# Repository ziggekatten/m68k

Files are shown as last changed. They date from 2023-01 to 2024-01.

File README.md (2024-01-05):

# Note to myself: I hate C pointers and macros.......
I have an blog where I will post my progress and thoughts when I have some spare time: https://brorson.se
# m68k
A overambitious project to build a usable computer from scratch. Based on bits and pieces from the interwebb, but with my own twists and turns. This main README will change frequently when I change my mind and decisions. 

It's not the goal that matters, is the journey....and it's true. Getting your thoughts and ideas into circuits and code is an iterative process, and for each success you get satisfaction. For every failure.....you get a reason for a big drink and rethink your decisions, just to fix the issue and start an new iteration. Add oh boy, the satisfaction when your idea works...priceless! 

Some decisions made from my part:

- Assembler is fun in small doses, so my plan is to NOT write firmware in assembler, but instead go down the C route and messing with sections and linkerscripts. Reason beeing that this will make me learn not only the various segments and the ELF format, but also how the GCC/LLVM toolchains works in more detail. I would like to use Zig (primary) or Rust (secondary), but as an non compiler wizard, this is currently on the backfoot, and O'l trusted C will do. There are some challenges though, that are quite simple in assembler, but when using C and segregation of duty, requires some more thoughts. For example, when using interrupts on the serial line, how do you pass the input from the exceptionhandler to your main kernel code? Simple answer one would say, some defined pseudo registers monitored by your main code in combination of global variables/structs in C. But this comes at an cost of CPU cycles as stuff needs to pass memory in several stages. Not easy decisions. Also, as I'm building some built in monitoring stuff in the firmwware to see values of stack pointer and register values, I might need to add som asssembler in the end. It will be inline if that's the case. It hurts, but unless I can use some GCC low level stuff I probably need to do this.
- Build my own stdlib based on newlib (https://sourceware.org/newlib/)
- Serial interface and an HW-monitor as initial I/0 path to the SBC 

Initial hardware:
- CPU: MC68010@12MHz
- DUART: MC68681
- 2 * 512K FLASH ROM
- 2 x 512K SRAM
- A bunch of 74LS/HCT chips
- A bunch of breadboards
- Some PAL/GAL's to replace discrete glue logic in the end
- Reset circuitry based on 555 timer and with both a reset button as well as an single step function, using DTACK.

## Some loose thoughts
- Use ELF as a base segment standard instead of Motorola S-records. This means that i need to steal someone elses ELF loader I guess... 
- When basic serial I/O is done. It's time to look at keyboard input as well as graphics display. The keyboard stuff is easy enough if using PS/2 standard. The graphics stuff however is a little bit more complicated. Signal wise it is easy, just output the correct voltages and Bob's your uncle. But getting data in a format that does not bog down CPU to some memory mapped hardware, and the get the display circuit to effectively interpret data and do stuff, is a different story. Text based stuff are easy using predetermined fonts, but The 680x0 CPU is not capable to feed pixel data at rates needed if just pushing pixels, so there have to be stuff in between. Amigas, Ataris and others have this done in custom chips, which means that I have to do it in an similar way. But this is where I draw the line (pun intended) and don't design my own blitter, copper etc. I will probably interface to already done parts, using APIs or existing hardware designs. In the end, designing at this level means also supply low level libraries and stuff. However, an pure vector based drawing design is in my head, so one never know....

## Memory map of the design
I keep it simple, and plan using the VBR register in the MC68010, so there is no shadowing or moving of ROM in my design.

| Address | Description |
|---|---|
| 0x00000000 - 0x000FFFFF | ROM ( 2 x 512K) |
| 0x00100000 - 0x001FFFFF | Onboard RAM (1 MB) |
| 0x00200000 - 0x00CFFFFF | Space for additional (14 MB) RAM |
| 0x00D00000 - | I/O space  (2 MB) | 
| 0x00D00000 - 0x00D0FFFF | DUART (64KB) |

## Codebase
I have switched to use https://github.com/tomstorey/m68k_bare_metal as base for my project instead of inventing all by myself. Sure, my linkerscript, Makefile and stuff was not bad, but was very bare bone. Even if there are a little more assembly, the structure is is more usable as defining exception vectors and stuff are easier. So instead of continuing and reinvent the wheel, I made the choice to use som clever stuff from github. Tom, you made me see a different (and more professional) way of doing stuff by the way you structured your code. Especially the linkerscript was an huge improvement over my amateur cocktail of C code.

All old firmware code are now in the /old_stuff folder and all new under /mb68k_bare_metal/mb68k
My headerfiles used for my specific board is located under /mb68k_bare_metal/include

## Version history
0.1.10 - Use of new approach for using C and design wise introducing buffers and more GALs 

0.1.9 - A lot of reshuffeling

0.1.8 - Switched to PlatformIO for Arduino stuff

0.1.7 - Got the firmware to configure DUART and spit out stuff on the terminal in sim68000 using pure C. Hardware is tested in an sense that I can control the DUART from an Arduiono Mega, and the CPU stuff on the breadboard is free running, and are awaiting the pairing of DUART and firmware code.

0.1.6 - Cleaned upp some code and added some README stuff. All prototypes now in headers.

0.1.5 - Just cleaning stuff

0.1.4 - Milestone. Got my bare Firmware (just ending in an loop) running in sim68000

0.1.3 - Just a bunch of renaming and updates of README files. In essence, cleaning up my own mess

0.1.2 - Milestone. I finally got the grips on gcc, linkerscripts, .map files etc. Building an ELF and object dump an binary now generates binary file with an valid reset vector and correct sections copied to RAM. What a fun ride it have been.

0.1.1 - Milestone. Got a free running CPU stepping through memory and blinking leds, by tying databus to ground (all zeros) throug pulldown resistors

## Toolchain(s) and emulators/simulators
Currently using GCC on Ubuntu 20.04 cross compiled for m68k.
In parallel building an LLVM toolchain for exploring the capabilities of using Rust and/or Zig instead of C. This is somewhat in an experimental phase, as some basic compilation efforts on LLVM and Rust/Zig is currently beeing tried out. My toolchains run in docker, and Dockerfiles can be found in the [toolchains] folder.

## Folder structure
| Folder | Description |
|---|---|
| code | Code for firmware and other stuff goes in here |
| kicad | KiCAD 7.x schematics |
| digital | Digital simulator for messing with glue logic and generation WinCUPL code in the end |
| toolchains | Things related to toolchains. Docker files etc |
| tests | Arduino stuff used to test and program various parts of the design |

## Some experiences to share

MC68000/10 memory mapping and external pheripherals are always an challenge. That said, the m68k has the most beautiful register/memory layout and assembler syntax known to man. If todays CPU's had this layout, ohh man... Normally external peripherals only use a few address lines and more importantly only half the data bus (unless on an MC68008). What this means is that you really need to understand how the processor address memory and in which order it's doing stuff. First of all, as you might have noted on the CPU there is no address line of 0. First physical address line is A1, which will cause som confusion to newbies (as it did to me!). To explain this we need to understand two other physical pins on the CPU: UDS and LDS. UDS means Upper Data Strobe, and LDS means Lower Data Strobe. These pins define if you are in the upper 8-bit or lower 8-bit of an word (16 bit). 

Now, this is what caught me, since the CPU is Big Endeian, even adresses is always the upper 8-bits. Easiest way of explain this is by starting at at the lowest address in hex: 0x00000000. This is an even address, and accessing this address will assert the UDS-pin signaling that the upper 8-bits of the data bus will be read/written from/to (bit 15-8). When designing your memory map, things can be confusing. Let us say that memory 0x00000000 to 0x000FFFFF is your first MB of RAM, and you think that address 0x00100000 is the first byte in the I/O space, you would be wrong. Address 0x00100000 is the upper 8-bits of the 16-bit word, and if you have the pheriperal connected to the D0-D7, the effective address is actually 0x00100001!. 

What this means is, that you need to take care when accessing 8-bit memory mapped peripherals. Let us take an simple example here using the MC68681 DUART chip as an example. It has an 4-bit addressing bus for it's registers that we normally connect to A1-A4, and an 8-bit address bus, connected to the A0-A7 physical bus. According to the documentation the registers are one byte in between on the chip itself. 

But this is not true in the scope of the CPU, as the most significant byte is never seen by the chip. It sees A1, not A0(UDS). In effect, this means that your code needs to have an offset of two(2) whereas the chip has an offset of only one(1).
In general, working with bytes is an pain as you need to think about alignment, and if possible use words....

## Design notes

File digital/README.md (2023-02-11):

## Memory map and glue logic
I use Digital (https://github.com/hneemann/Digital) to do alot of digital circuit designs, and it also have the very conveniant feature of generating circuits from truth tables, and then create .JED files for the GAL's that I'm using (GAL22v10D from Lattice).

| File | Description |
|---|---|
| address_decoder_gal.tru | Truth table for address decoding meant for GAL22v10D |
| memorydecoding.dig | This is an design based on multiplexers (74LS138) instead of an GAL |

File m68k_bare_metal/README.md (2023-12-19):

# Bare Metal m68k Cross Compiler "Toolchain"
- [Bare Metal m68k Cross Compiler "Toolchain"](#bare-metal-m68k-cross-compiler--toolchain-)
  * [Motivation](#motivation)
  * [My solution](#my-solution)
  * [How To Use](#how-to-use)
    + [Get started (installation)](#get-started-installation)
    + [Build libmetal](#build-libmetal)
    + [Create a "project"](#create-a-project)
    + [Linker script](#linker-script)
    + [Write some code already...](#write-some-code-already...)
    + [Notes about floating point](#notes-about-floating-point)
  * [Additional tools](#additional-tools)
- [Advanced Topics](#advanced-topics)
  * [Default interrupt handler](#default-interrupt-handler)
  * [Exception handling routines](#exception-handling-routines)
  * [Interrupt Service Routines](#interrupt-service-routines)
- [Anything Else](#anything-else)
  * [TODOs](#todos)

This repository contains my efforts to create an "idiot proof bare metal m68k cross compiler toolchain of sorts."

Please be advised that I am not a makefile or linker script expert in any way, and the fact this works at all may just be sheer luck. If you have suggestions how I can better or more properly achieve what I have, I would be very appreciative to hear from you. In the mean time, please be gentle. :-)

## Motivation
There are a lot of tools out there that can create cross compiler environments for all sorts of architectures on all sorts of architectures. If you work as a software developer, these tools might make a lot of sense, and may be the right way to go about things.

But as a lowly hobbyist that dabbles in both software and hardware and is certainly a master of neither, I find these tools quite complicated and often hard to get my head around what they are doing and how to use them. I want something simpler.

## My Solution
My solution to the problem was to create something (hopefully) so simple that ideally anyone else like me out there could understand how it is working, and also be able to modify it to suit their needs.

In my solution, I want to take some C source files (and perhaps some assembly source files, too), compile them, link them together, and produce a binary image out the other side that can be loaded directly into ROM and placed into a system and run.

To achieve this I have made a minimal linker script that allows you to position and dimension your ROM and RAM memories as required. The linker script also pulls in a reasonably vanilla flavoured `crt0` that I made, and creates the exception vector table (including reset vector).

Also included is a `Makefile` to help make building your code easier. Essentially the only thing you need to do with the Makefile is list each of the object file names that will be linked together to produce your binary (the compiler, `gcc` in my case, takes care of working out the details including dependencies for C source files).

Other than that, you just start writing code and run `make`! I think that's pretty simple.

## How To Use
There are two different "build environment flavours" that you can choose from:

 - **standalone**: this is a build that will run by itself on your system. It will include a exception vector table (EVT), and program code (crt0, your code, read only/constant data, initialised variables)
 - **application**: this is a build that might, for example, run along side a standalone build. This kind of build includes all of the above with the exception of a pared down crt0 and excludes the EVT

The idea behind these two different builds comes down to how you might build and write software for a bare metal system. For example, you may use a standalone build to implement some kind of operating system or monitor, and perhaps this allows you to load in code over a serial link and execute it. That code may be some kind of application that you want to test and debug, and which itself does not require an EVT.

### Get started (installation)
You can build or install the required tools on a variety of operating systems. Installation instructions are broken out by operating system (or group of) as each is a little different to the last, so please refer to the appropriate INSTALL-xxxx.md file in this repo.

At the time of writing, the tool chain is known to work on the following operating systems:

 - Ubuntu 18.04 and 20.04
 - Debian 9.12 and 10
 - Windows 10 with WSL
 - macOS High Sierra (10.13), Catalina (10.15), Big Sur (11.6)

### Build libmetal
libmetal is just a "libc like library" that I have put together including a lot of standard libc style functions. Included is a `printf` (credit: https://github.com/eyalroz/printf) and `malloc` (credit: own work, inspired by FreeRTOS).

libmetal should only need to be built once per CPU type, and is then used in all of your future projects using that CPU. If further source files or changes to source files are made within libmetal, then you will need to rebuild it for each CPU type that you intend to use.

To build libmetal, simply run `make` within the `libmetal` directory. Provided there are no blocking errors, you will be left with a file called `libmetal-xxxx.a` (where xxxx is the CPU type), and at that point you are done.

Dont forget to modify the CPU type and select your gcc prefix in the `Makefile` as required - the CPU type influences the output filename, as each copy of libmetal is built specific to that CPU.

### Create a "project"
Really this is just as simple as making a copy of either the `standalone` or `application` directory, and naming it appropriately. You'll then work on the files in this directory.

```
~$ cd m68k_bare_metal
~/m68k_bare_metal$ cp -a standalone myproject
~/m68k_bare_metal$ cd myproject
~/m68k_bare_metal/myproject$ ls -la
-rw-r--r-- 1 tom tom 1456 May 31 14:52 Makefile
-rw-r--r-- 1 tom tom 3376 May 31 14:52 crt0.S
-rw-r--r-- 1 tom tom   54 May 31 14:52 main.c
-rw-r--r-- 1 tom tom 5540 May 31 14:52 platform.ld
```

Open `Makefile` in your favourite editor and modify the CPU and PREFIX variables as required for your target and environment.

Once you have done this, the first thing to do is to assemble `crt0.S`. Take a quick look at the very beginning of this file and determine if there are any settings that you want to change for your situation, otherwise, run:

```
~/m68k_bare_metal/myproject$ make crt
```

You'll then notice a file called `crt.o` in your project directory. This object file is needed by the linker, and is the first code that will execute when the system starts up. `crt0` is responsible for (in a standalone build):

* ensuring interrupts are masked by default
* setting up the stack pointer (manually, notes included)
* copying the EVT to RAM at address 0 or configuring the VBR as/if required
* copying the values of initialised variables into their appropriate memory locations
* clearing the .bss section
* calling soft and hard initialisation hooks

After all of this, it then jumps to your `main()` routine. In an application build, `crt0` only copies initialised variables into RAM, zeroises the .bss section (uninitialised variables) and jumps to `main()`.

### Linker script
The default linker script configuration places ROM at address 0 with a size of 0x100000 (1 megabyte), and RAM at 0x100000 with a size of 0x100000. Space is also reserved for the stack which is initialised to the top of RAM, and all remaining space will be allocated to the heap.

You may need to modify these values to suit your system and application memory layout and requirements. If you do, be sure to `make clean` and rebuild your project to ensure that the new memory layout is updated in your binary. It is not necessary to rebuild crt0 if you simply modify the memory layout.

To do this, open `platform.ld` in your preferred editor, and look at the `base` and `sz` variables at the top of the file. Modify these as required.

 - `base` refers to the very first memory address of that memory type
 - `sz` refers to the number of bytes provided by that memory

The SSP (Supervisor Stack Pointer) will be initialised to the very top of memory, thus assuming that the stack grows downwards with pre-decrement. Therefore, in the default configuration, the SSP will point to 0x200000, and the first value to be pushed to the stack will be written to 0x1FFFFC (long) or 0x1FFFFE (word).

The initial PC (Program Counter) value will point to the address of `_start`, which is located in `crt0.S`.

The linker script also generates an exception vector table (EVT), and this will be located through addresses 0-0x3FF (0-1023) in the ROM. Each entry in the EVT is a long (4 bytes) which points to an address where the code that handles that exception or interrupt is located. When an interrupt or execption occurrs, the processor reads the corresponding EVT entry and then jumps to the address contained within.

Both the SSP and initial PC values are stored as the very first two longs in the EVT, e.g. from addresses 0-7.

All of the documented exception vectors are pre-configured in the linker script, but if you need to add more, e.g. for your UARTs and other devices, then they can be defined manually in the linker script. See the documentation included within the linker script for an example of how to do that.

Note that while the ROM does not have to always exist from address 0, it will need to exist there initially as the m68k needs to read the SSP and initial PC values starting from address 0. If you require RAM to be located at address 0 in your system, you will need to implement circuitry or some software means to switch the ROM to a higher address. You will also then need to ensure that address range 0-0x3FF in RAM is populated with the EVT required for your system - `crt0` largely takes care of this automatically by either setting the Vector Base Register (VBR) on CPUs that have it, or copying the EVT.

These are the only changes to the linker script required, but you are free to experiment if you wish (or dare).

### Write some code already...
Ok, with all of the setup of your environment completed, you can now being to write code.

Included is a very simple `main.c`, so you can test that everything is working simply by running `make`. If all is successful, you should see a file called `bmbinary`.

```
~/m68k_bare_metal/myproject$ make
m68k-linux-gnu-gcc -m68000 -Wall -g -static -I. -msoft-float -MMD -MP -c -o main.o main.c
m68k-linux-gnu-ld -o bmbinary main.o --script=platform.ld
~/m68k_bare_metal/myproject$ ls -la
-rw-r--r-- 1 tom tom  1456 May 31 14:52 Makefile
-rwxrwxr-x 1 tom tom 19056 May 31 14:54 bmbinary
-rw-rw-r-- 1 tom tom  2136 May 31 14:53 crt0.o
-rw-r--r-- 1 tom tom  3376 May 31 14:52 crt0.S
-rw-r--r-- 1 tom tom    54 May 31 14:52 main.c
-rw-rw-r-- 1 tom tom    15 May 31 14:54 main.d
-rw-rw-r-- 1 tom tom  2112 May 31 14:54 main.o
-rw-r--r-- 1 tom tom  5540 May 31 14:52 platform.ld
```

If this works without any errors you are off to a very good start. From here you can proceed to write further code, and create additional source files. Worth noting, dependencies for .c files are automatically generated.

For each source file that you create, you will need to add it to `Makefile` in order for it to be compiled and linked.

Fortunately this is a very simple process, and all you need to do is add what will be the corresponding object filename (.o) to a variable at the top of the Makefile. Instructions are included to demonstrate how you should do this.

Once you are finished writing code and are ready to run it in your system, running `make rom` will output a file called `bmbinary.rom` which can be written to your ROMs and installed in the system.

### Notes about floating point
Most 68000 family CPUs do not include a floating point unit, and many systems do not include an external FPU either. Getting soft float to work in this toolchain has been a challenge, and I'm still not quite there yet. If you are able to help get this working, I'd love to hear from you!

Long story short, floating point may or may not work!

## Additional tools
The Makefile includes some extra rules to help with your development, these are:

 - `make dump` displays a disassembly of `bmbinary`
 - `make dumps` displays a disassembly of `bmbinary` with source code intermixed
 - `make hexdump` will produce a hex dump of `bmbinary.rom`
 - `make clean` will remove all `.o`, `.d`, and the `bmbinary` and `bmbinary.rom` files from your project directory (except `crt0.o`)

# Advanced Topics
**Note:** Most of what is written below applies only to standalone builds, as application builds do not include an EVT.

## Default interrupt handler
By default, all documented exception vectors will point to a default interrupt handling routine, which is included in `crt0.S`, called `__DefaultInterrupt`.

The default handler simply halts the CPU and masks all IRQs below IRQ7, but this is not likely to be the desired behaviour that a user may want. Therefore, the user needs to create their own service routines to handle them.

The linker script builds the EVT based on the presence or absence of each expected service routine. If a service routine is not defined, then its vector table entry points to `__DefaultInterrupt`, otherwise the entry points to the address of the routine in the ROM image.

You can of course modify or override `__DefaultInterrupt` if you desire some other default behaviour.

## Exception handling routines
If you look in `platform.ld` you will see a list of all of the exception handling routine names that are expected. These can be changed if you would prefer different names.

To ensure that your code handles each exception in the way you would prefer, simply create a routine with the name as described in the linker script. For example, if you would like to handle a divide by zero exception, you would create the following routine:

```c
void __attribute__((interrupt))
ZeroDivide(void)
{
    /* Your code here */
}
```

Exception handlers do not return a value, so they are void. They also do not take any parameters. `__attribute__((interrupt))` tells the compiler to insert the correct return instruction, `rte` instead of `rts`, when returning from an interrupt.

If you were to then run `make` and then `make dump` to view the disassembly, you would notice that the EVT has been populated with an entry that points to the ZeroDivide routine you created, for example:

```
~/m68k_bare_metal/myproject$ make dump
...
Contents of section .evt:
 0010 00000470 00000482 00000470 00000470  ...p.......p...p...
00000482 <ZeroDivide>:
 482:   4e56 0000       linkw %fp,#0
 486:   4e71            nop
 488:   4e5e            unlk %fp
 48a:   4e73            rte
 ...
```

As you can see, rather than pointing to the default interrupt handler at 0x00000470, one entry corresponding to the divide by zero exception now points to 0x00000482.

And thats basically all there is to that. Happy error handling!

## Interrupt Service Routines
To handle a vectored interrupt, you must create an ISR, and also create the appropriate vector table entry in the linker script.

To begin with, in your C file, you can create your ISR as follows:

```c
void __attribute__((interrupt))
my_interrupt_handler(void)
{
    /* Your code here */
}
```

And like exception handlers, ISRs return nothing and have no parameters, so are void. Likewise, the interrupt attribute tells the compiler to use the correct return instruction for this routine.

Now, in the linker script you will need to create an entry to be placed in the EVT. Documentation is included, but lets use another example. Say we want our interrupt vector to be 0x80, we would create our entry as follows:

 - Vector numnber 0x80
 - Multiply by 4 to get a physical address of 0x200
 - Results in origin of 0x200 within the `.evt` section

Therefore we add the following to the linker script:

```
SECTIONS {
	...
    .evt : {
	...
        . = 0x200;
        LONG(ABSOLUTE(my_interrupt_handler));
    } > evt
	...
}
```

Re-compiling our code and inspecting the disassembly we should then expect to see something like the following:

```
~/m68k_bare_metal/myproject$ make dump
...
Contents of section .evt:
 0200 0000048c                             ....
...
0000048c <my_interrupt_handler>:
 48c:   4e56 0000       linkw %fp,#0
 490:   4e71            nop
 492:   4e5e            unlk %fp
 494:   4e73            rte
	...
```

Happy interrupt vectoring!

# Anything Else
Please file an issue with me for any questions you have, I'll do my best to help.

## TODOs
 - Integrate a GDB stub for debugging

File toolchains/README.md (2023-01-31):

# Toolchains and simulators/emulators!

Some useful stuff related to Simulators nad toolchains. Let us start with...

## Simulators
Yes, especially simulators are gold when developing for homebrew hardware. Popping flash ROM in an out of breadboards are tedious, and by chance I stumbled over the sim6000 simulator. An simulator written in C++ and Tcl/tk, but it has two brilliant features:
- Simulation of an mc68681 DUART, with selectable base address! This is golden to test stuff in software. Loads Motorola S-records and of you go. 
- Multiple definable memory areas

The code can be found at: https://github.com/BSVC/bsvc
clone, make and make install and you are up and running. Requires wish and xterm though (apt install xterm wish on Ubuntu or in my case, latest version of Pop!_OS), and the UI...well, time have not been friendly to this app....but it works! It booted my firmware completely written in C. Now I can start messing with serial stuff. It comes with ssome samples including Tutor(!) using an xterm as serial I/O.

TODO: Maybe evolve this codebase and udate UI???

Apart from that, the EASy68k emulator is a good tool if you are into assembler and no pheripherals. The UI is WAY better than sim68000, but no peripherals built in. You can find it here: http://www.easy68k.com/

## Toolchains

Instead of messing up your local linux install or VM's, usage of containers is an pragmatic way for running toolchains.
Several options exists, and this repo have currently three different ones to pick from. Two versions of LLVM for future use of zig and/or rust instead of C.
Third option is to use the toolchan created by: https://rosco-m68k.com/ 

- Dockerfile.15: LLVM 1.15.x build with m68k support. To be used with zig (experimental and not complete!!!)
- Dockerfile.16: LLVM 1.16.x build with m68k support. To be used with rust (experimental and not complete!!!)
- Dockerfile.rosco: A containerized implementation of Rosco SBC toolchain https://rosco-m68k.com/docs/toolchain-installation

Are you an Windows purist and don't use Docker, WSL or an Linux VM, there is an precompiled setup available at: https://gnutoolchains.com/m68k-elf. Built with older versions f GCC and newlib, but still a working toolchain.

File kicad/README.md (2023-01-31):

# Hardware design

Basic principles:
- Use of buffers when in doubt. The 68010 pins can't drive that much current 

TODO: description

- CPU: MC68010@12MHz
- DUART: MC68681
- 2 * 512K FLASH ROM
- 2 x 512K SRAM

## Memory map

TODO: description

| Start address (hex) | End address (hex) | Usage |
|:---:|:---:|:---:|
|0x00100000 |0x00200000 | Onboard RAM |
|0x00000000 |0x00100000 | Onboard ROM |

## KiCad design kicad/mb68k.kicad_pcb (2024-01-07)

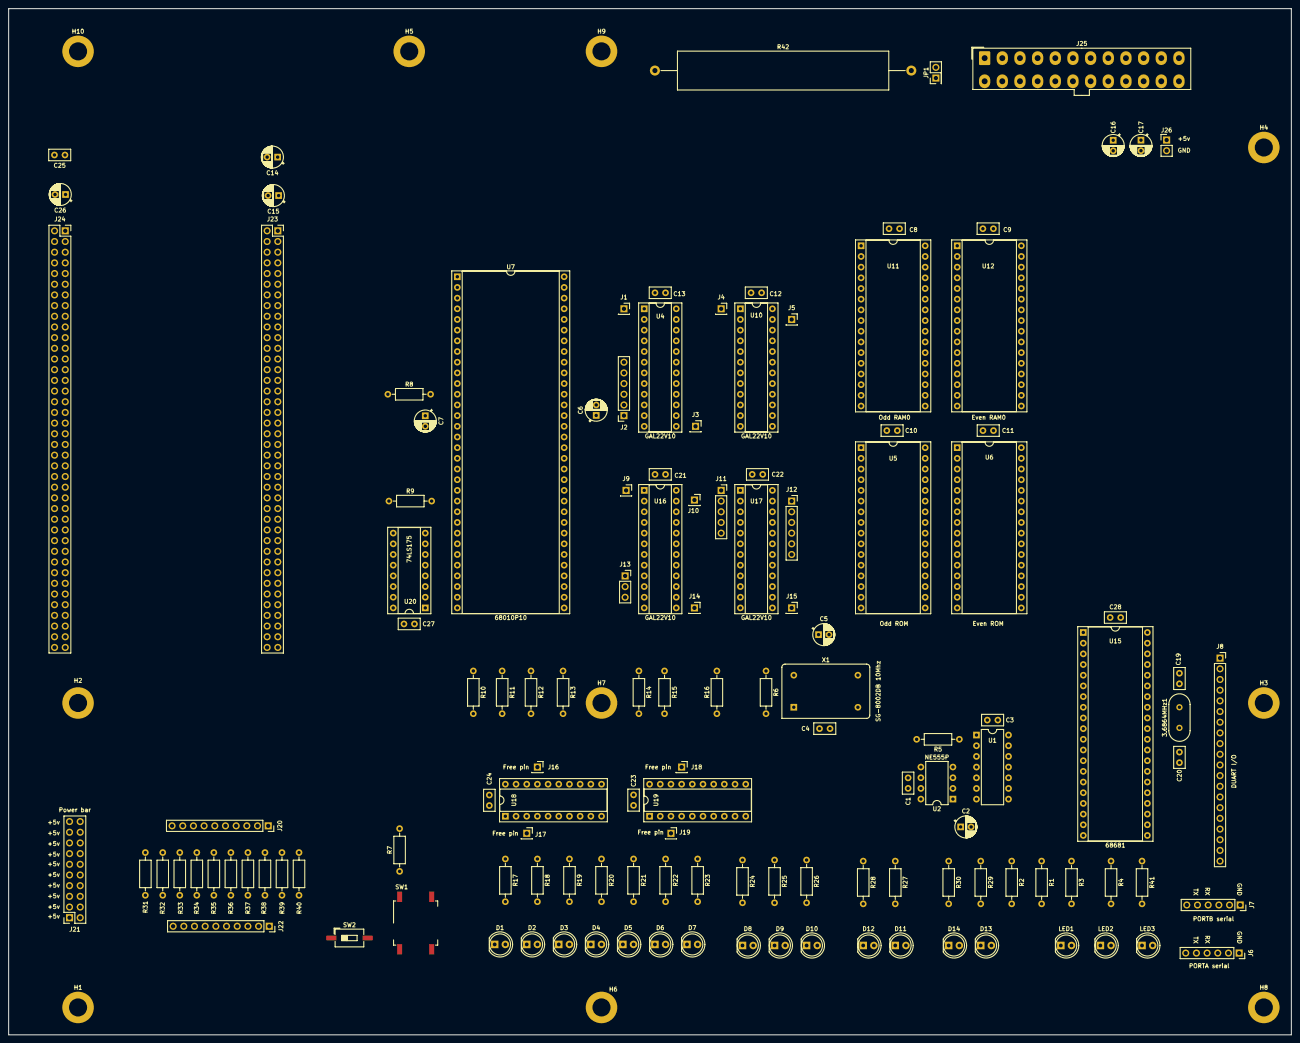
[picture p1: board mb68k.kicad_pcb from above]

Board: 4 copper layers, 305.0 x 244.0 mm, 142 parts (0 on the bottom side), 199 nets, no tracks yet.

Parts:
3.6864MHz1: Crystal; Crystal_HC18-U_Vertical
C1, C3, C4, C8, C9, C10, C11, C12, C13, C21, C22, C23, C24, C27, C28: 100nF; C_Disc_D5.0mm_W2.5mm_P2.50mm
C2, C16: 100uF; CP_Radial_D5.0mm_P2.50mm
C5, C6, C7, C15, C26: 100nF; CP_Radial_D5.0mm_P2.50mm
C14: 10uF; CP_Radial_D5.0mm_P2.50mm
C17: 470uF; CP_Radial_D5.0mm_P2.50mm
C19, C20: 7pF; C_Disc_D5.0mm_W2.5mm_P2.50mm
C25: 10uF; C_Disc_D5.0mm_W2.5mm_P2.50mm
D1: IRQ1; LED_D5.0mm
D2: IRQ2; LED_D5.0mm
D3: IRQ3; LED_D5.0mm
D4: IRQ4; LED_D5.0mm
D5: IRQ5; LED_D5.0mm
D6: IRQ6; LED_D5.0mm
D7: IRQ7; LED_D5.0mm
D8: FC1; LED_D5.0mm
D9: FC2; LED_D5.0mm
D10: FC3; LED_D5.0mm
D11: DUARTA_RX; LED_D5.0mm
D12: DUARTA_TX; LED_D5.0mm
D13: DUARTB_RX; LED_D5.0mm
D14: DUARTB_TX; LED_D5.0mm
H1, H2, H3, H4, H5, H6, H7, H8, H9, H10: MountingHole_Pad; MountingHole_4.3mm_M4_DIN965_Pad
J1, J3, J4, J5, J9, J10, J14, J15, J16, J17, J18, J19: Free pin; PinSocket_1x01_P2.54mm_Vertical
J2, J12: Free pins; PinSocket_1x06_P2.54mm_Vertical
J6: PORTA serial; PinSocket_1x06_P2.54mm_Vertical
J7: PORTB serial; PinSocket_1x06_P2.54mm_Vertical
J8: DUART I/O; PinSocket_1x20_P2.54mm_Vertical
J11: Free Pins; PinSocket_1x05_P2.54mm_Vertical
J13: Free pins; PinSocket_1x03_P2.54mm_Vertical
J20, J22: Spare resistors; PinSocket_1x10_P2.54mm_Vertical
J21: Power bar; PinSocket_2x10_P2.54mm_Vertical
J23: BUS Slot 2; PinSocket_2x40_P2.54mm_Vertical
J24: BUS Slot 1; PinSocket_2x40_P2.54mm_Vertical
J25: ATX-24; Molex_Mini-Fit_Jr_5566-24A_2x12_P4.20mm_Vertical
J26: External Power; PinHeader_1x02_P2.54mm_Vertical
JP1: BASE LOAD; PinHeader_2x01_P2.54mm_Vertical
LED1: RED Reset; LED_D5.0mm
LED2: GREEN Run; LED_D5.0mm
LED3: GREEN PWR; LED_D5.0mm
R1, R2, R6: 4K7; R_Axial_DIN0207_L6.3mm_D2.5mm_P10.16mm_Horizontal
R3, R4: 330R; R_Axial_DIN0207_L6.3mm_D2.5mm_P10.16mm_Horizontal
R5: 2K2; R_Axial_DIN0207_L6.3mm_D2.5mm_P10.16mm_Horizontal
R7: 270R; R_Axial_DIN0207_L6.3mm_D2.5mm_P10.16mm_Horizontal
R8, R9, R10, R11, R12, R13, R14, R15, R16, R31, R32, R33, R34, R35, R36, R37, R38, R39, R40: 4k7; R_Axial_DIN0207_L6.3mm_D2.5mm_P10.16mm_Horizontal
R17, R18, R19, R20, R21, R22, R23, R24, R25, R26, R27, R28, R29, R30, R41: R330; R_Axial_DIN0207_L6.3mm_D2.5mm_P10.16mm_Horizontal
R42: R10 14W; R_Axial_Power_L50.0mm_W9.0mm_P60.96mm
SW1: HW_RESET_SW; SW_MEC_5GSH9
SW2: POWER ON; SW_DIP_SPSTx01_Slide_6.7x4.1mm_W8.61mm_P2.54mm_LowProfile
U1: 74LS05; DIP-14_W7.62mm
U2: NE555P; DIP-8_W7.62mm
U4, U10, U16, U17: GAL22V10; DIP-24_W7.62mm_Socket
U5, U6: SST39SF040; DIP-32_W15.24mm_Socket
U7: 68010P10; DIP-64_W25.4mm_Socket
U11, U12: AS6C4008-55PCN; DIP-32_W15.24mm_Socket
U15: 68681; DIP-40_W15.24mm_Socket
U18, U19: 74LS244; DIP-20_W7.62mm_Socket
U20: 74LS175; DIP-16_W7.62mm_Socket
X1: SG-8002DB 10Mhz; Oscillator_DIP-14

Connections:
A1: J23.47, J24.47, U5.12 (A0), U6.12 (A0), U7.29 (A1), U11.12 (A0), U12.12 (A0), U15.1 (RS1), U16.5 (I4)
A2: J23.45, J24.45, U5.11 (A1), U6.11 (A1), U7.30 (A2), U11.11 (A1), U12.11 (A1), U15.3 (RS2), U16.6 (I5)
A3: J23.43, J24.43, U5.10 (A2), U6.10 (A2), U7.31 (A3), U11.10 (A2), U12.10 (A2), U15.5 (RS3), U16.7 (I6)
A4: J23.41, J24.41, U5.9 (A3), U6.9 (A3), U7.32 (A4), U11.9 (A3), U12.9 (A3), U15.6 (RS4)
A5: J23.39, J24.39, U5.8 (A4), U6.8 (A4), U7.33 (A5), U11.8 (A4), U12.8 (A4)
A6: J23.37, J24.37, U5.7 (A5), U6.7 (A5), U7.34 (A6), U11.7 (A5), U12.7 (A5)
A7: J23.35, J24.35, U5.6 (A6), U6.6 (A6), U7.35 (A7), U11.6 (A6), U12.6 (A6)
A8: J23.33, J24.33, U5.5 (A7), U6.5 (A7), U7.36 (A8), U11.5 (A7), U12.5 (A7)
A9: J23.31, J24.31, U5.27 (A8), U6.27 (A8), U7.37 (A9), U11.27 (A8), U12.27 (A8)
A10: J23.29, J24.29, U5.26 (A9), U6.26 (A9), U7.38 (A10), U11.26 (A9), U12.26 (A9)
A11: J23.27, J24.27, U5.23 (A10), U6.23 (A10), U7.39 (A11), U11.23 (A10), U12.23 (A10)
A12: J23.25, J24.25, U5.25 (A11), U6.25 (A11), U7.40 (A12), U11.25 (A11), U12.25 (A11)
A13: J23.23, J24.23, U5.4 (A12), U6.4 (A12), U7.41 (A13), U11.4 (A12), U12.4 (A12)
A14: J23.21, J24.21, U5.28 (A13), U6.28 (A13), U7.42 (A14), U11.28 (A13), U12.28 (A13)
A15: J23.19, J24.19, U5.29 (A14), U6.29 (A14), U7.43 (A15), U11.3 (A14), U12.3 (A14)
A16: J23.17, J24.17, U5.3 (A15), U6.3 (A15), U7.44 (A16), U10.10 (I9), U11.31 (A15), U12.31 (A15)
A17: J23.15, J24.15, U5.2 (A16), U6.2 (A16), U7.45 (A17), U10.11 (I10), U11.2 (A16), U12.2 (A16)
A18: J23.13, J24.13, U5.30 (A17), U6.30 (A17), U7.46 (A18), U10.14 (I/O), U11.30 (A17), U12.30 (A17)
A19: J23.11, J24.11, U5.1 (A18), U6.1 (A18), U7.47 (A19), U10.15 (I/O), U11.1 (A18), U12.1 (A18)
A20: J23.9, J24.9, U7.48 (A20), U10.2 (I1)
A21: J23.7, J24.7, U7.50 (A21), U10.3 (I2)
A22: J23.5, J24.5, U7.51 (A22), U10.4 (I3)
A23: J23.3, J24.3, U7.52 (A23), U10.5 (I4)
CLK: J23.4, J24.4, U7.15 (CLK), X1.8 (OUT)
D0: J23.40, J24.40, U5.13 (D0), U7.5 (D0), U11.13 (DQ0), U15.25 (D0)
D1: J23.38, J24.38, U5.14 (D1), U7.4 (D1), U11.14 (DQ1), U15.16 (D1)
D2: J23.36, J24.36, U5.15 (D2), U7.3 (D2), U11.15 (DQ2), U15.24 (D2)
D3: J23.34, J24.34, U5.17 (D3), U7.2 (D3), U11.17 (DQ3), U15.17 (D3)
D4: J23.32, J24.32, U5.18 (D4), U7.1 (D4), U11.18 (DQ4), U15.23 (D4)
D5: J23.58, J24.58, U5.19 (D5), U7.64 (D5), U11.19 (DQ5), U15.18 (D5)
D6: J23.60, J24.60, U5.20 (D6), U7.63 (D6), U11.20 (DQ6), U15.22 (D6)
D7: J23.62, J24.62, U5.21 (D7), U7.62 (D7), U11.21 (DQ7), U15.19 (D7)
D8: J23.64, J24.64, U6.13 (D0), U7.61 (D8), U12.13 (DQ0)
D9: J23.66, J24.66, U6.14 (D1), U7.60 (D9), U12.14 (DQ1)
D10: J23.68, J24.68, U6.15 (D2), U7.59 (D10), U12.15 (DQ2)
D11: J23.70, J24.70, U6.17 (D3), U7.58 (D11), U12.17 (DQ3)
D12: J23.72, J24.72, U6.18 (D4), U7.57 (D12), U12.18 (DQ4)
D13: J23.74, J24.74, U6.19 (D5), U7.56 (D13), U12.19 (DQ5)
D14: J23.76, J24.76, U6.20 (D6), U7.55 (D14), U12.20 (DQ6)
D15: J23.78, J24.78, U6.21 (D7), U7.54 (D15), U12.21 (DQ7)
E: U7.20 (E), U20.9 (Cp)
FC0: U7.28 (FC0), U16.2 (I1), U19.2 (I0a)
FC1: U7.27 (FC1), U16.3 (I2), U19.4 (I1a)
FC2: U7.26 (FC2), U16.4 (I3), U19.6 (I2a)
GND: C2.2, C3.2, C4.2, C5.2, C6.2, C7.2, C8.2, C9.2, C10.2, C11.2, C12.2, C13.2, C14.2, C15.2, C16.2, C17.2, C19.1, C20.1, C21.2, C22.2, C23.2, C24.2, C25.2, C26.2, C27.1, C28.2, H1.1, H2.1, H3.1, H4.1, H5.1, H6.1, H7.1, H8.1, H9.1, H10.1, J6.1, J7.1, J8.1, J21.2, J21.4, J21.6, J21.8, J21.10, J21.12, J21.14, J21.16, J21.18, J21.20, J23.2, J23.42, J24.2, J24.42, J25.3 (GND), J25.5 (GND), J25.7 (GND), J25.15 (GND), J25.17 (GND), J25.18 (GND), J25.19 (GND), J25.24 (GND), JP1.1 (A), R7.2, R24.1, R25.1, R26.1, R27.1, R28.1, R29.1, R30.1, R41.1, SW2.1 (A), U1.7 (GND), U2.1 (GND), U4.12 (GND), U5.16 (GND), U6.16 (GND), U7.16 (GND), U7.53 (GND), U10.12 (GND), U11.16 (VSS), U12.16 (VSS), U15.20 (GND), U16.12 (GND), U17.12 (GND), U18.1 (OEa), U18.10 (GND), U18.19 (OEb), U19.1 (OEa), U19.10 (GND), U19.19 (OEb), U20.8 (GND), X1.7 (GND)
IP0: J8.2, U15.7 (IP0)
IP1: J8.3, U15.4 (IP1)
IP2: J8.4, U15.36 (IP2)
IP3: J8.5, U15.2 (IP3)
IP4: J8.6, U15.39 (IP4)
IP5: J8.7, U15.38 (IP5)
unnamed: D1.2 (A), R17.2
unnamed: D1.1 (K), U18.18 (O0a)
unnamed: D2.2 (A), R18.2
unnamed: D2.1 (K), U18.16 (O1a)
unnamed: D3.2 (A), R19.2
unnamed: D3.1 (K), U18.14 (O2a)
unnamed: D4.2 (A), R20.2
unnamed: D4.1 (K), U18.12 (O3a)
unnamed: D5.2 (A), R21.2
unnamed: D5.1 (K), U18.9 (O0b)
unnamed: D6.2 (A), R22.2
unnamed: D6.1 (K), U18.7 (O1b)
unnamed: D7.2 (A), R23.2
unnamed: D7.1 (K), U18.5 (O2b)
unnamed: D8.2 (A), U19.18 (O0a)
unnamed: D8.1 (K), R24.2
unnamed: D9.2 (A), U19.16 (O1a)
unnamed: D9.1 (K), R25.2
unnamed: D10.2 (A), U19.14 (O2a)
unnamed: D10.1 (K), R26.2
unnamed: D11.2 (A), U19.12 (O3a)
unnamed: D11.1 (K), R27.2
unnamed: D12.2 (A), U19.9 (O0b)
unnamed: D12.1 (K), R28.2
unnamed: D13.2 (A), U19.7 (O1b)
unnamed: D13.1 (K), R29.2
unnamed: D14.2 (A), U19.5 (O2b)
unnamed: D14.1 (K), R30.2
unnamed: J1.1, U4.1 (I0/CLK)
unnamed: J2.1, U4.11 (I10)
unnamed: J2.2, U4.10 (I9)
unnamed: J2.3, U4.9 (I8)
unnamed: J2.4, U4.8 (I7)
unnamed: J2.5, U4.7 (I6)
unnamed: J2.6, U4.6 (I5)
unnamed: J3.1, U4.13 (I11)
unnamed: J4.1, U10.1 (I0/CLK)
unnamed: J5.1, U10.23 (I/O)
unnamed: J9.1, U16.1 (I0/CLK)
unnamed: J10.1, U16.23 (I/O)
unnamed: J11.1, U17.1 (I0/CLK)
unnamed: J11.2, U17.2 (I1)
unnamed: J11.3, U17.3 (I2)
unnamed: J11.4, U17.4 (I3)
unnamed: J11.5, U17.5 (I4)
unnamed: J12.1, U17.23 (I/O)
unnamed: J12.2, U17.22 (I/O)
unnamed: J12.3, U17.21 (I/O)
unnamed: J12.4, U17.20 (I/O)
unnamed: J12.5, U17.19 (I/O)
unnamed: J12.6, U17.18 (I/O)
unnamed: J13.1, U16.9 (I8)
unnamed: J13.2, U16.10 (I9)
unnamed: J13.3, U16.11 (I10)
unnamed: J14.1, U16.13 (I11)
unnamed: J15.1, U17.13 (I11)
unnamed: J16.1, U18.17 (I3b)
unnamed: J17.1, U18.3 (O3b)
unnamed: J18.1, U19.17 (I3b)
unnamed: J19.1, U19.3 (O3b)
unnamed: J20.1, R40.2
unnamed: J20.2, R39.2
unnamed: J20.3, R38.2
unnamed: J20.4, R37.2
unnamed: J20.5, R36.2
unnamed: J20.6, R35.2
unnamed: J20.7, R34.2
unnamed: J20.8, R33.2
unnamed: J20.9, R32.2
unnamed: J20.10, R31.2
unnamed: J22.1, R40.1
unnamed: J22.2, R39.1
unnamed: J22.3, R38.1
unnamed: J22.4, R37.1
unnamed: J22.5, R36.1
unnamed: J22.6, R35.1
unnamed: J22.7, R34.1
unnamed: J22.8, R33.1
unnamed: J22.9, R32.1
unnamed: J22.10, R31.1
unnamed: J25.16 (PS_ON#), SW2.2 (B)
unnamed: J25.8 (PWR_OK), LED3.2 (A)
unnamed: JP1.2 (B), R42.2
unnamed: LED1.2 (A), R3.2
unnamed: LED2.2 (A), R4.2
unnamed: LED2.1 (K), U1.6
unnamed: LED3.1 (K), R41.2
unnamed: R7.1, SW1.1
unnamed: C2.1, R5.2, SW1.3 (K), U2.2 (TR), U2.6 (THR)
unnamed: C1.2, U2.5 (CV)
unnamed: U1.1, U1.3, U2.3 (Q)
unnamed: R8.2, U7.12 (BGACK), U7.13 (BR), U7.21 (VPA)
unnamed: 3.6864MHz1.1, C20.2, U15.32 (X1/CLK)
unnamed: 3.6864MHz1.2, C19.2, U15.33 (X2)
unnamed: U20.2 (Q0), U20.5 (D1)
unnamed: U20.7 (Q1), U20.12 (D2)
unnamed: U20.10 (Q2), U20.13 (D3)
unnamed: R6.2, X1.1 (OE)
OP0: J8.12, U15.29 (OP0)
OP1: J8.13, U15.12 (OP1)
OP2: J8.14, U15.28 (OP2)
OP3: J8.15, U15.13 (OP3)
OP4: J8.16, U15.27 (OP4)
OP5: J8.17, U15.14 (OP5)
OP6: J8.18, U15.26 (OP6)
OP7: J8.19, U15.15 (OP7)
RXDA: J6.4, J8.10, U15.31 (RXDA), U19.8 (I3a)
RXDB: J7.4, J8.8, U15.10 (RXDB), U19.13 (I1b)
R/~W: U4.4 (I3), U7.9 (R/W), U10.8 (I7)
TXDA: J6.5, J8.11, U15.30 (TXDA), U19.11 (I0b)
TXDB: J7.5, J8.9, U15.11 (TXDB), U19.15 (I2b)
VCC: C1.1, C3.1, C4.1, C5.1, C6.1, C7.1, C8.1, C9.1, C10.1, C11.1, C12.1, C13.1, C14.1, C15.1, C16.1, C17.1, C21.1, C22.1, C23.1, C24.1, C25.1, C26.1, C27.2, C28.1, J8.20, J21.1, J21.3, J21.5, J21.7, J21.9, J21.11, J21.13, J21.15, J21.17, J21.19, J23.1, J23.49, J24.1, J24.49, J25.4 (+5V), J25.6 (+5V), J25.21 (+5V), J25.22 (+5V), J25.23 (+5V), J26.1, J26.2, R1.1, R2.1, R3.1, R4.1, R5.1, R6.1, R8.1, R9.1, R10.1, R11.1, R12.1, R13.1, R14.1, R15.1, R16.1, R17.1, R18.1, R19.1, R20.1, R21.1, R22.1, R23.1, R42.1, U1.14 (VCC), U2.4 (R), U2.8 (VCC), U4.24 (VCC), U5.31 (PGM), U5.32 (VCC), U6.31 (PGM), U6.32 (VCC), U7.14 (VCC), U7.49 (VCC), U10.24 (VCC), U11.32 (VCC), U12.32 (VCC), U15.40 (VCC), U16.24 (VCC), U17.24 (VCC), U18.20 (VCC), U19.20 (VCC), U20.16 (VCC), X1.14 (Vcc)
_AS: U4.19 (I/O), U20.1 (~Mr), U20.4 (D0)
_R/~W: J23.20, J24.20, U4.16 (I/O), U11.29 (WE#), U12.29 (WE#), U15.8 (R/W)
_W/~R: U4.18 (I/O), U5.24 (OE), U6.24 (OE), U11.24 (OE#), U12.24 (OE#)
~AS: U4.2 (I1), U7.6 (AS), U10.13 (I11), U16.8 (I7)
~BERR: R9.2, U7.22 (BERR), U20.14 (~Q3)
~CSEVENRAM0: U10.19 (I/O), U12.22 (CE#)
~CSEVENROM: U6.22 (CE), U10.17 (I/O)
~CSODDRAM0: U10.18 (I/O), U11.22 (CE#)
~CSODDROM: U5.22 (CE), U10.16 (I/O)
~DTACK: J23.12, J24.12, U7.10 (DTACK), U10.21 (I/O), U15.9 (DTACK)
~DUARTSEL: U10.20 (I/O), U15.35 (CS)
~EXTSEL: J23.18, J24.18, U10.22 (I/O)
~HALT: R2.2, U1.4, U1.5, U7.17 (HALT)
~IACK1: J23.63, J24.63, U16.15 (I/O)
~IACK2: J23.61, J24.61, U16.16 (I/O)
~IACK3: J23.59, J24.59, U16.17 (I/O)
~IACK4: J23.57, J24.57, U16.19 (I/O)
~IACK5: J23.55, J24.55, U15.37 (IACK), U16.20 (I/O)
~IACK6: J23.53, J24.53, U16.21 (I/O)
~IACK7: J23.51, J24.51, U16.18 (I/O), U16.22 (I/O)
~IPL0: U7.25 (IPL0), U17.15 (I/O)
~IPL1: U7.24 (IPL1), U17.16 (I/O)
~IPL2: U7.23 (IPL2), U17.17 (I/O)
~IRQ1: J23.56, J24.56, R10.2, U17.6 (I5), U18.2 (I0a)
~IRQ2: J23.54, J24.54, R11.2, U17.7 (I6), U18.4 (I1a)
~IRQ3: J23.52, J24.52, R12.2, U17.8 (I7), U18.6 (I2a)
~IRQ4: J23.50, J24.50, R13.2, U17.9 (I8), U18.8 (I3a)
~IRQ5: J23.48, J24.48, R14.2, U15.21 (IRQ), U17.10 (I9), U18.11 (I0b)
~IRQ6: J23.46, J24.46, R15.2, U17.11 (I10), U18.13 (I1b)
~IRQ7: J23.44, J24.44, R16.2, U17.14 (I/O), U18.15 (I2b)
~LDS: U4.3 (I2), U7.8 (LDS), U10.7 (I6)
~RESET: LED1.1 (K), R1.2, U1.2, U7.18 (RESET), U15.34 (RESET)
~UDS: U4.5 (I4), U7.7 (UDS), U10.9 (I8)
~_AS: J23.26, J24.26, U4.14 (I/O)
~_LDS: J23.22, J24.22, U4.15 (I/O)
~_UDS: J23.24, J24.24, U4.17 (I/O)

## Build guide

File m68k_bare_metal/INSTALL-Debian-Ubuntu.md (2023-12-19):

# Installation on Ubuntu and Debian
Fortunately, Ubuntu and Debian seem to be quite similar, so the same instructions apply for both of these OSes, and are quite straight forward:

```
~$ sudo su -
[sudo] password for tom:
~# apt install git
~# apt install gcc-m68k-linux-gnu
~# apt install make
~# exit
logout
~$
```

From here, clone my repository to grab all of the files you need.

```
~$ git clone https://github.com/tomstorey/m68k_bare_metal.git
```

The repo will be cloned into a directory called `m68k_bare_metal`.

And that is all that is required for installation.

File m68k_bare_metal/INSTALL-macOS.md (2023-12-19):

# Installation on macOS
The installation procedure for macOS is a bit more involved, and will require building of the `gcc` and `binutils` packages from source.

Fortunately I found a script by someone else that makes this procedure relatively painless, requiring only a couple of manual steps to be performed. Full credit to them is noted at the top of the script itself, I only had to make minor adjustments for what seem to be some minor changes in the years since that script was released.

The first step is to make sure that you have `brew` installed. Follow the installation instructions on the brew website: [https://brew.sh/](https://brew.sh/)

brew will install the command line developer tools which will include `git`, so this does not need to be installed separately. You may want to check which version has been installed, and if required, visit the git website to download an installer for a more recent version for example.

[https://git-scm.com/](https://git-scm.com/)

With these two requirements taken care of, clone the repository:

```
~ % git clone https://github.com/tomstorey/m68k_bare_metal.git
```

And then run the `macos-build-toolchain.sh` script.

```
~ % cd m68k_bare_metal
m68k_bare_metal % ./macos-build-toolchain.sh
```

**Note:** You may need to attend the installation, as I noticed on my Mac that some printer dialogs popped up... I'm not sure why, but I had to close them as they would pause the build while waiting for you to do something.

When the build has completed successfully, you can remove two temporary directories that were created (this will free up around 2GB of disk space):

```
m68k_bare_metal % rm -rf toolchain/build toolchain/sources
```

You will find that a new directory has been created, called `toolchain/m68k-eabi-elf-x.x.x` (where x.x.x is the GCC version number that has been built). Inside here are the various binaries that were built in the process above. Each toolchain is contained within its own directory, so it is possible to retain multiple different versions if the need should arise.

The only thing left to do is to modify the Makefiles to point to the binaries that have been built on your Mac. You'll want to modify the `Makefile`s within the `standalone` and `application` directories, so that any projects you create from these will incorporate the changes.

Inside each Makefile, you will find the `PREFIX` variable towards the top. This is the initial part of the filename for each of the various binaries that are called within the Makefile, e.g. the compiler, assembler, linker etc. The prefix and the remaining portion of the binary name are concatenated to form a series of variables that are the full binary name.

Modify the PREFIX variable to point to the binaries that have been compiled on your Mac, e.g.

```
PREFIX=~/m68k_bare_metal/toolchain/m68k-eabi-elf-x.x.x/bin/m68k-eabi-elf
```

You could instead modify your `PATH` environment variable instead of specifying an absolute path within the Makefiles - I leave this as an exercise for the user. :-)

And that should be it for installing on macOS!

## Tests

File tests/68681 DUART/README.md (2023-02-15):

## Arduino code for testing MC68681 DUART
Here you find an PlatformIO project that uses serial monitor for learning the 68681 chip. I use an Arduino Mega 2560, and hook up RESET, DTACKN, RW, CE, Register Select (address) and databus. Then use serial input to run some functions to configure the DUART. In this way I can learn what to do without flashing ROMs and try things out on the real 68k CPU. Uploading an sketch is so much simpler.....

One thing to note is that my design uses buffers (74LS244 and 74LS245), as can be seen in the Kicad diagrams. Since I plan to use buffers, this have been part of my breadboard running my testing with Arduino.

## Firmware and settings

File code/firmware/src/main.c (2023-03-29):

/**
* @Author: Mats Brorson
* @Date: 2023-01-27
* 
* @Description: Main program used for the built in firmware monitor features. This is an stepping stone into a future OS of
* some kind. But that is way in the future. All things here will be done using Supervisor mode
*/
#include <stdint.h>
#include "include/hwdefs.h"
#include "include/mc68681.h"
#include "include/utils.h"

void _fmain(void)
{
/* Plans and notes here are:
* - define layout of stuff
* - Avoid assembly as long as possible
* - Help function by typing ? (question mark) I need an parser...
* - define commands to be used. Base it on concept of opcode and operands? like "cd 0x300" to change to that address and thereafter commands
    are based from that adress? Memory filesystem-ish? Hmmmm.... treating addresses as directories based on words? Files a byte? Interesting...but is it effective?
* - execute program from adress
* - dump registers and memory/ROM contents. Needs assembly code....
* - change memory data(really?)
* - Breakpoints with traps or trace feature of CPU
* - diagnostics of hardware
* - change VBR. This might not be an good idea....
*/
    char *text = "SRA: ";
    char *nl = "\r\n->";
    char memaddr[8];
    serial_putstr(text);
    //uint8_t addr = (uint8_t)*DUART_SRA;
    uint8_t addr = DUART_SRA;
    char * outp = itohexa(memaddr, addr);
    serial_putstr(outp);
    serial_putstr(nl);

    text = "MR1A: ";
    serial_putstr(text);
    addr = DUART_MR1A;
    outp = itohexa(memaddr, addr);
    serial_putstr(outp);
    serial_putstr(nl);

    text = "MR2A: ";
    serial_putstr(text);
    addr = DUART_MR1A;
    outp = itohexa(memaddr, addr);
    serial_putstr(outp);
    serial_putstr(nl);

    text = "RBA: ";
    serial_putstr(text);
    addr = DUART_RBA;
    outp = itohexa(memaddr, addr);
    serial_putstr(outp);
    serial_putstr(nl);
    
    char *inputbuf = "Got a keypress!\r\n";
    while(1) {
        uint8_t test = DUART_RBA;
        if (test != 7) {
        for (int i = 0; inputbuf[i] != '\0'; i++) { 
            serial_putchar(inputbuf[i]);
            //if (DUART_SRA == 0x00) {
            //    inputbuf = DUART_RBA;
            //    serial_putchar(*inputbuf);         
            } 
        }
    }
}

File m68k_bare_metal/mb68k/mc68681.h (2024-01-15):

/**
 * @author (c) Mats Brorson ()
 *             2023-2024, Sweden
 *
 * 
 * @brief Function prototypes to initialize and start serial communications, and
 * configure timers and other features of the Motorola MC68681 chip.
 * 
 * @license The MIT License (MIT)
 *
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
 * THE SOFTWARE IS PROVIDED "AS IS", WITHOUT WARRANTY OF ANY KIND, EXPRESS OR
 * IMPLIED, INCLUDING BUT NOT LIMITED TO THE WARRANTIES OF MERCHANTABILITY,
 * FITNESS FOR A PARTICULAR PURPOSE AND NONINFRINGEMENT. IN NO EVENT SHALL THE
 * AUTHORS OR COPYRIGHT HOLDERS BE LIABLE FOR ANY CLAIM, DAMAGES OR OTHER
 * LIABILITY, WHETHER IN AN ACTION OF CONTRACT, TORT OR OTHERWISE, ARISING FROM,
 * OUT OF OR IN CONNECTION WITH THE SOFTWARE OR THE USE OR OTHER DEALINGS IN
 * THE SOFTWARE.
 */


#ifndef MB68K_MC68681_H_
#define MB68K_MC68681_H_
/* 
* DUART register definition using a base addres from hardware header file and adds some offsets
* Depending on read or write, the use of register changes for some offsets! Keep in mind two things:
    - Pointers, pointers, pointers....Using pure values in constructor as base for pointers in .c file fails miserably. Defining
        pointers in the header file seems to work. Must be my lack of C knowledge why this is. Spent hours debugging
        assembly output before finding that values was sent to registers as values and not as references until defining
        things as pointers in the header files.
    - Odd adressing is key as only lower 8 bits are connected
*/
#define DUART_MR1A      ((volatile uint8_t *)DUART_BASE+0x01)  // Mode Register Port A. first read or write (MR1A)
#define DUART_MR2A      ((volatile uint8_t *)DUART_BASE+0x01)  // Mode Register Port A. second read or write (MR1A)
#define DUART_SRA       ((volatile uint8_t *)DUART_BASE+0x03)  // Status Register A 
#define DUART_CSRA      ((volatile uint8_t *)DUART_BASE+0x03)  // Clock-Select Register A 
#define DUART_CRA       ((volatile uint8_t *)DUART_BASE+0x05)  // Command Register A. Remember to wait until command is done!!
#define DUART_RBA       ((volatile uint8_t *)DUART_BASE+0x07)  // Receive Buffer A 
#define DUART_TBA       ((volatile uint8_t *)DUART_BASE+0x07)  // Transmit Buffer A 
#define DUART_IPCR      ((volatile uint8_t *)DUART_BASE+0x09)  // Input Port Change Register 
#define DUART_ACR       ((volatile uint8_t *)DUART_BASE+0x09)  // Auxiliary Control Register 
#define DUART_ISR       ((volatile uint8_t *)DUART_BASE+0x0B)  // Interrupt Status Register 
#define DUART_IMR       ((volatile uint8_t *)DUART_BASE+0x0B)  // Interrupt Mask Register 
#define DUART_CUR       ((volatile uint8_t *)DUART_BASE+0x0D)  // Counter Mode: current MSB 
#define DUART_CTUR      ((volatile uint8_t *)DUART_BASE+0x0D)  // Counter/Timer upper reg 
#define DUART_CLR       ((volatile uint8_t *)DUART_BASE+0x0F)  // Counter Mode: current LSB 
#define DUART_CTLR      ((volatile uint8_t *)DUART_BASE+0x0F)  // Counter/Timer lower reg 
#define DUART_MR1B      ((volatile uint8_t *)DUART_BASE+0x11)  // Mode Register Port B. first read or write (MR1B) 
#define DUART_MR2B      ((volatile uint8_t *)DUART_BASE+0x11)  // Mode Register Port B. second read or write (MR2B) 
#define DUART_SRB       ((volatile uint8_t *)DUART_BASE+0x13)  // Status Register B 
#define DUART_CSRB      ((volatile uint8_t *)DUART_BASE+0x13)  // Clock-Select Register B 
#define DUART_CRB       ((volatile uint8_t *)DUART_BASE+0x15)  // Command Register B 
#define DUART_RBB       ((volatile uint8_t *)DUART_BASE+0x17)  // Receive Buffer B 
#define DUART_TBB       ((volatile uint8_t *)DUART_BASE+0x17)  // Transmit Buffer A 
#define DUART_IVR       ((volatile uint8_t *)DUART_BASE+0x19)  // Interrupt Vector Register 
#define DUART_IP        ((volatile uint8_t *)DUART_BASE+0x1B)  // Input Port 
#define DUART_OPCR      ((volatile uint8_t *)DUART_BASE+0x1B)  // Output Port Configuration Reg. 
#define DUART_STRTCC    ((volatile uint8_t *)DUART_BASE+0x1D)  // Start-Counter command 
#define DUART_OPRSET    ((volatile uint8_t *)DUART_BASE+0x1D)  // Output Port Reg, SET bits 
#define DUART_STOPCC    ((volatile uint8_t *)DUART_BASE+0x1F)  // Stop-Counter command 
#define DUART_OPRRST    ((volatile uint8_t *)DUART_BASE+0x1F)  // Output Port Reg, ReSeT bits

// MC68681 Command Numbers
#define CMD_RESET_MR			0x10
#define CMD_RESET_RX			0x20
#define CMD_RESET_TX			0x30
#define CMD_RESET_ERROR			0x40
#define CMD_ENABLE_TX_RX		0x05
#define CMD_ENABLE_RX			0x01
#define CMD_DISABLE_RX			0x02
#define CMD_ENABLE_TX			0x04
#define CMD_DISABLE_TX			0x08
#define CMD_START_BREAK			0x60
#define CMD_STOP_BREAK			0x70


// MC68681 Default Configuration Values
#define MR1A_MODE_A_REG_1_CONFIG	    0b10010011	// RxRTS Enabled, 8 bits, No Parity
#define MR2A_MODE_A_REG_2_CONFIG	    0b00000111	// Normal mode, CTS Disabled, 1 stop bit
#define CSRA_CLK_SELECT_REG_A_CONFIG	0b11001100	// 38400 bps @ 3.6864MHz
#define ACR_AUX_CONTROL_REG_CONFIG	    0b01111000	// Set1, External Clock / 16, IRQs disabled except IP3


// Status Register Bits (SRA/SRB)
#define SR_RECEIVED_BREAK		0x80
#define SR_FRAMING_ERROR		0x40
#define SR_PARITY_ERROR			0x20
#define SR_OVERRUN_ERROR		0x10
#define SR_TX_EMPTY			    0x08
#define SR_TX_READY			    0x04
#define SR_RX_FULL			    0x02
#define SR_RX_READY			    0x01

/* 
* prototype for initializing Serial commmunication function in DUART. Should
* probably should return something to indicate if it was successful
* TODO:
* prototypes for (and expose as symbols for those to be configurable in userspace later on)
* 1. Reset reciever, transmitter, error status, mode register pointer (CRA)
* 2. configure data bit, parity in the mode register (MR1A)
* 3. configure flow control ans stop bits in mode register (MR2A)
* 4. configure baud rate
* 5. enable Rx and Tx (CRA)
* 6. set ACR[7] = 0
* 7. disable interrupt
* Rmove dependencies to hwdefs in this header for reusability
*/
void serial_init_default_port(void);       // for initialize default settings at boot. In effect, running below functions
void serial_init(void);                    // Reset of chip
void serial_flow_control(void);            // Set up flow control
void serial_baud_rate(void);               // Set up baudrate
void serial_enable(void);                  // Enable tranciever and reciever

/* Function: serial_putchar: Sends a char to the DUART
* arguments: char to output
* returns: int) 0 if all ok. 
*/
int serial_putchar(char ch);

/* Function: serial_getchar: Gets a char to the DUART 
* parameters: 
* returns: char from DUART buffer.
* TODO: Interrupt and handler to run this function?
*/
char serial_getchar();

void serial_putstr(char *);

#endif

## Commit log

2022-02-06 initial messing with digital and kicad
    [68k.kicad_pcb, 68k.kicad_sch, untitled.kicad_sch]
2023-01-26 cleanup of a mess on my desktop
    [68k.kicad_pcb, 68k.kicad_sch, CPU.kicad_sch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]
2023-01-27 Added vectors
    [CPU.kicad_sch, Reset.kicad_sch, mb68k.kicad_sch]
2023-01-30 Some prototype changes
2023-02-01 Adjuste arduino code
2023-02-01 Adjusted arduino with high impedence
2023-02-03 Added arduino DUART testcode
2023-02-06 Arduino and kicad work
    [DUART.kicad_sch, Reset.kicad_sch, mb68k.kicad_sch]
2023-02-07 revamped arduino stuff
2023-02-11 Lot of stuff. Memmory decoder in GAL Added README for Digital Updated sketch for Arduino
    [DUART.kicad_sch, mb68k.kicad_sch]
2023-02-13 KiCad updates
    [CPU.kicad_sch, DUART.kicad_sch, Reset.kicad_sch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]
2023-02-15 switched to PlatformIO fromArduino IDE
2023-02-15 Removed old arduino stuff
2023-02-15 Arduino tweaks
2023-02-15 Update kicad
    [CPU.kicad_sch, Reset.kicad_sch, mb68k.kicad_sch]
2023-02-16 started with pcb
    [CPU.kicad_sch, DUART.kicad_sch, Reset.kicad_sch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]
2023-02-16 Update footprint
    [CPU.kicad_sch, DUART.kicad_sch, Reset.kicad_sch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]
2023-12-25 Revamped gluelogic for IRQ and DTACK
    [CPU.kicad_sch, dtack_irq.kicad_sch]
2023-12-25 Fixing bugs
    [dtack_irq.kicad_sch]
2023-12-28 - Added buffers for LED indicators in kicad - Removed pullups on FC0.2 in kicad - Connected FC0-2 to glue logic in kicad - Revamped glue logic for irg and iack in Digital
    [CPU.kicad_sch, dtack_irq.kicad_sch, indicators.kicad_sch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]
2023-12-29 New decoding and GALs
    [CPU.kicad_sch, DUART.kicad_sch, Reset.kicad_sch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]
2024-01-01 Added Bus error handling
    [CPU.kicad_sch, DUART.kicad_sch, busarb.kicad_sch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]
2024-01-02 switched to GALasm
    [CPU.kicad_sch, DUART.kicad_sch, busarb.kicad_sch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]
2024-01-02 finalized signaling PLD
    [dtack_irq.kicad_sch, mb68k.kicad_sch]
2024-01-02 added footprints
    [CPU.kicad_sch, DUART.kicad_sch, Reset.kicad_sch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]
2024-01-06 PCB to ATX size
    [CPU.kicad_sch, DUART.kicad_sch, Reset.kicad_sch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]
2024-01-07 saving state
    [CPU.kicad_sch, Reset.kicad_sch, busarb.kicad_sch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]
2024-01-07 saved again
    [DUART.kicad_sch, freerouting.dsn, indicators.kicad_sch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]
2024-01-07 saving kicad
2024-01-09 fiddlign with placement
    [CPU.kicad_sch, DUART.kicad_sch, dtack_irq.kicad_sch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]
2024-01-14 got irq to work
    [CPU.kicad_sch, DUART.kicad_sch, Reset.kicad_sch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]
